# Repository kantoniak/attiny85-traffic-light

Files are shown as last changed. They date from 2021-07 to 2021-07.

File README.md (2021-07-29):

# ATTINY85 traffic light

A simple traffic light implemented using ATTINY85. Lights cycle between configurations and user can move to the next one by pressing a button.

<p align="center">
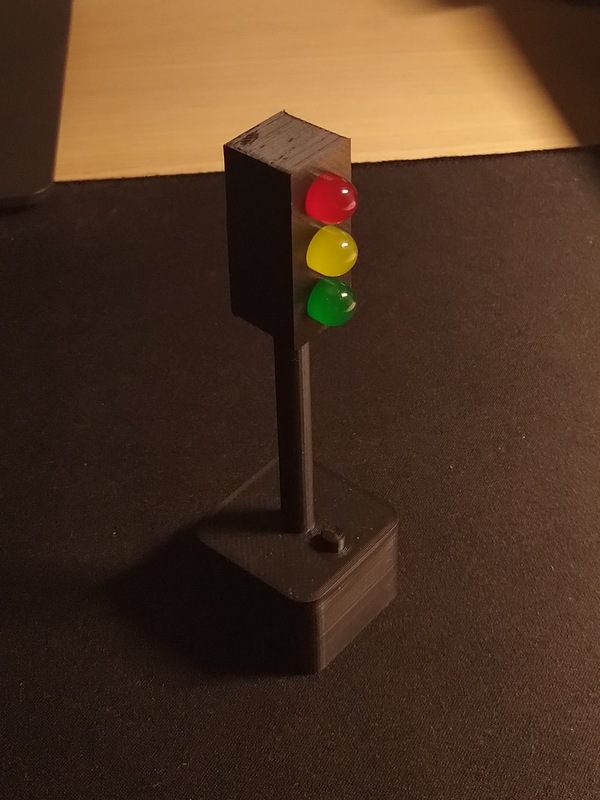
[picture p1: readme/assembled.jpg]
    
</p>

## Hardware

### Electronics

I used big, 10 mm LEDs. The green one has ~3.15V forward voltage and thus the second battery. You don't need it for regular LEDs.

Schematic

BOM:
* ATTINY85 in DIP package;
* 8-leg DIP socket;
* 10 mm LEDs: red, yellow, green;
* 1k, 1k, 330 ohm resistors;
* tactile switch with a pull-up resistor;
* an ON-OFF switch;
* 2x CR2032 battery;
* 20 mm wide PCB.

### Case

Consists of multiple parts for 3D printing in PLA. Print with 20% infill, without supports. See `case/` for Fusion 360 files and exported STLs.

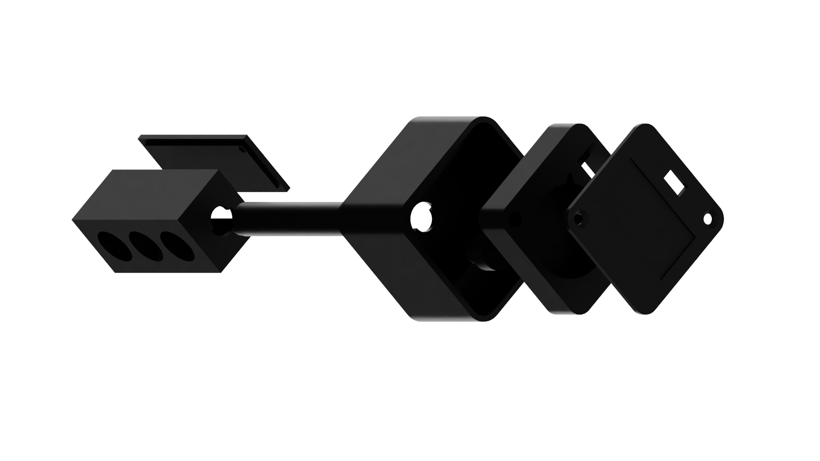
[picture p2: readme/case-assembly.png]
Case render


I wanted to make ATTINY85 replaceable and over-engineered a bit.

Case Assembly BOM:
* 2x M2.5x20 flat-head screw (DIN 965);
* 4x M2x12 flat-head screw (DIN 965);
* 4x M2 hex nuts;
* 2x M2.5 threaded insert, height up to 10 mm (goes into the base);
* 2x M2 threaded insert, height up to 6 mm (goes into the lights back);
* 2x office clip 🙂 (cut and bend to make CR2032 contacts).

## Software

The code is a PlatformIO project. It basically cycles between states after a timeout. The states are as follows, with possible actions marked with colors:
State graph
User can manually move to the next state by pressing a button (the red cycle).
μC will enter deep sleep after 10 minutes since last button press.

### Energy savings

The light runs on a single CR2032 cell capacity (about 220 mAh), so it should consume minimal amounts of energy. Current optimizations are:

* Deep sleep after 10 minutes (commit 0f1c727)
* Disabled ADC (commit dee5303, [blog post](http://www.technoblogy.com/show?KX0))
* Unused pins set to `LOW` (commit dee5303, [forum post](http://gammon.com.au/power))
* Custom fuses settings (commit 2d93b48, [fuse calculator](https://www.engbedded.com/fusecalc/))
  * disabled Brown-Out Detection which does some voltage comparisons
  * 1 MHz clock speed from diving 8 MHz by 8

Remember to set fuses from PlatformIO! It doesn't happen automatically during upload.

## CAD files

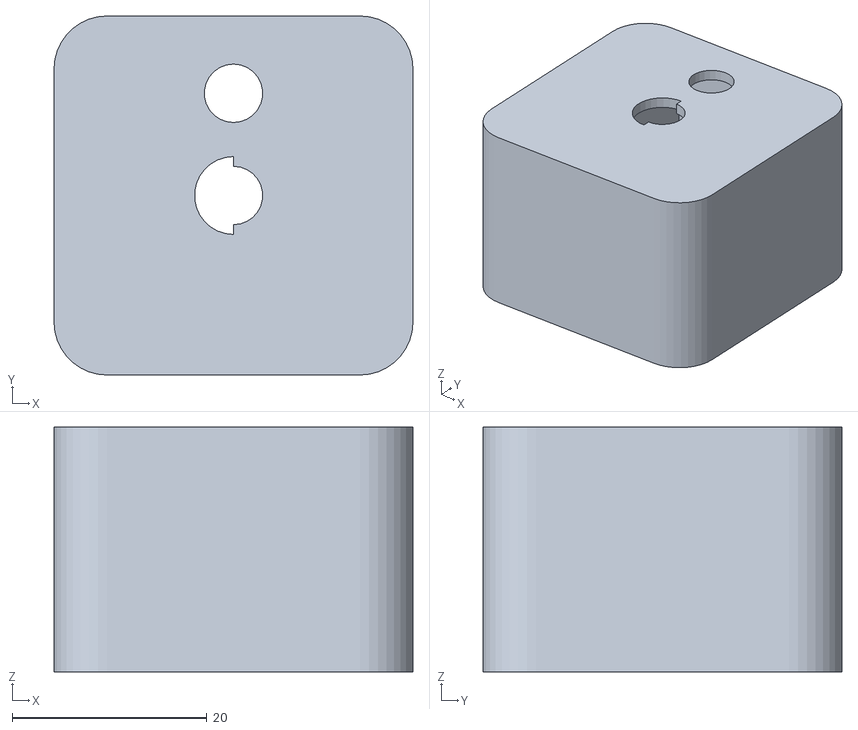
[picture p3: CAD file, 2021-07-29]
case/base.stl
36.9 x 36.9 x 25.1

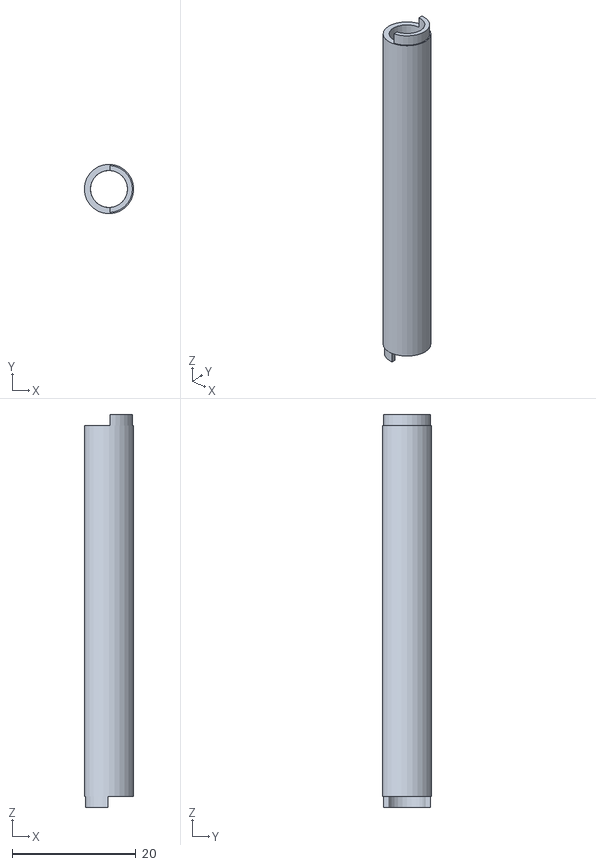
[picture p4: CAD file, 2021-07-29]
case/pole.stl
8.00 x 8.00 x 63.6

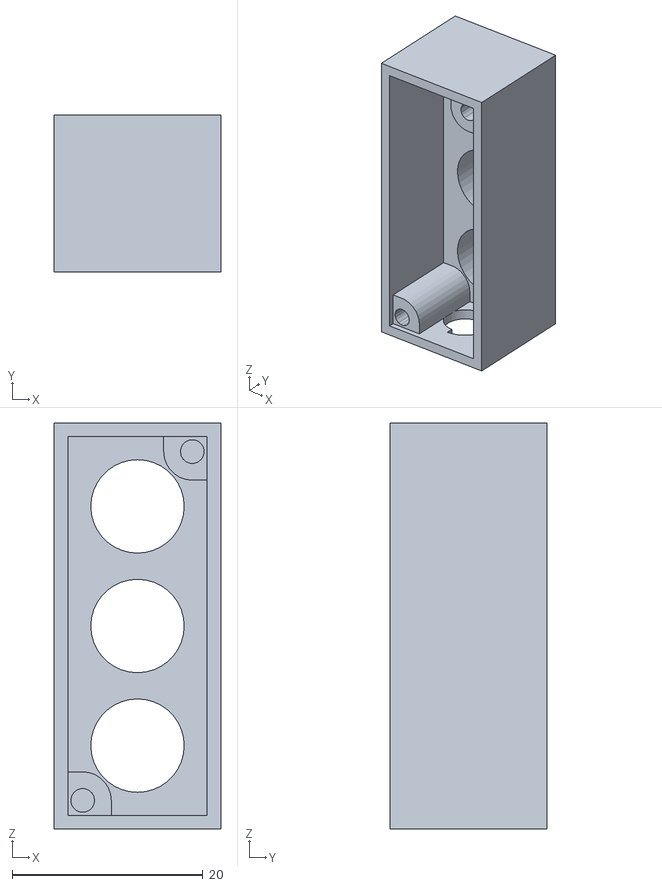
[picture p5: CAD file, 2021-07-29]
case/front.stl
17.5 x 16.5 x 42.6

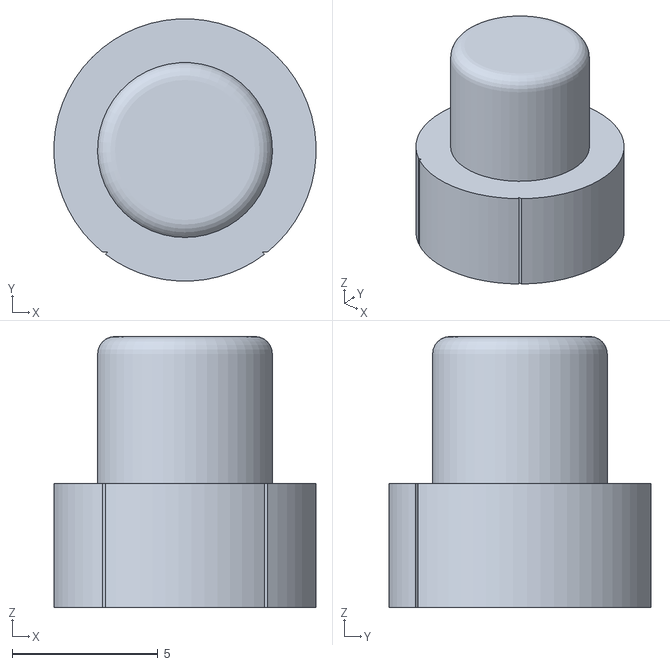
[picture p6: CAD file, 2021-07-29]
case/button.stl
8.99 x 8.99 x 9.30

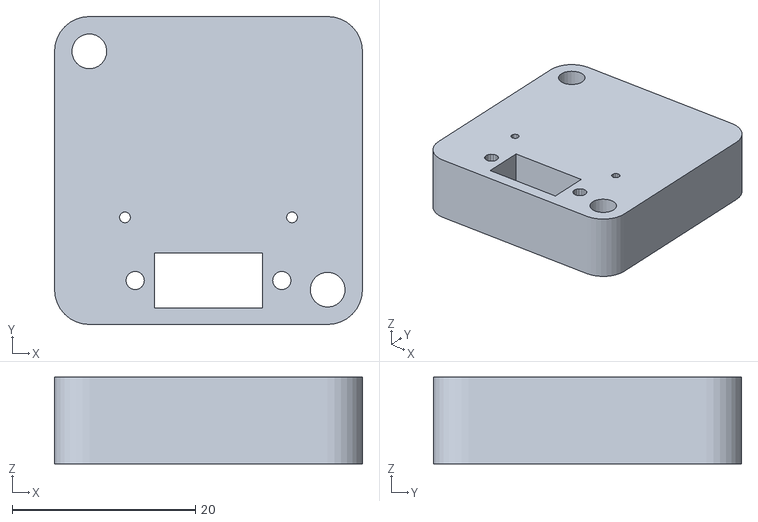
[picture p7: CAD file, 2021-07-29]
case/battery-holder.stl
33.6 x 33.6 x 9.44

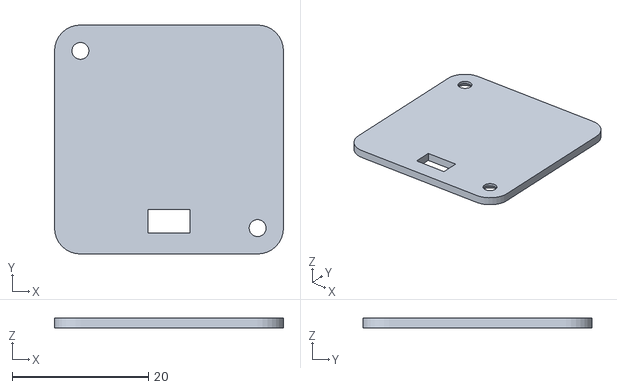
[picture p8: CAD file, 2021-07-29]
case/battery-cover.stl
33.6 x 33.6 x 1.44

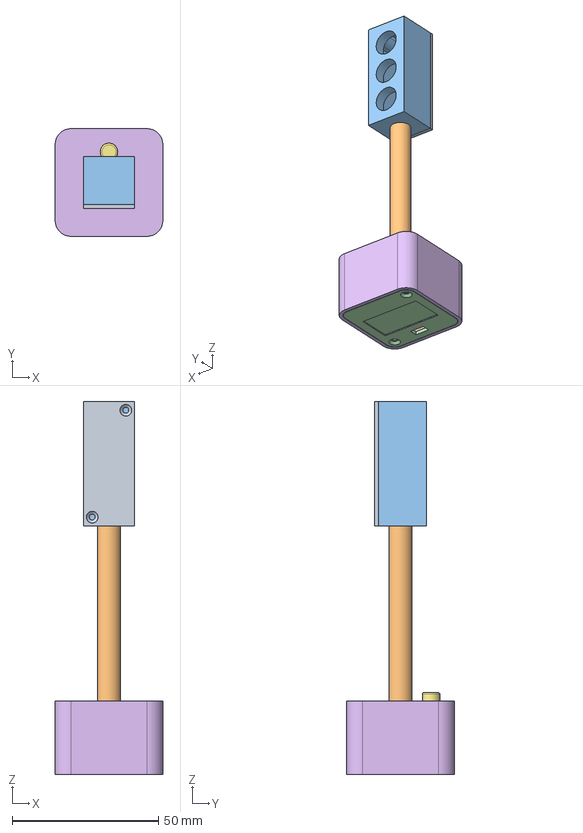
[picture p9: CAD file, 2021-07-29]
case/attiny85-traffic-light.step
36.9 x 36.9 x 127.7 mm

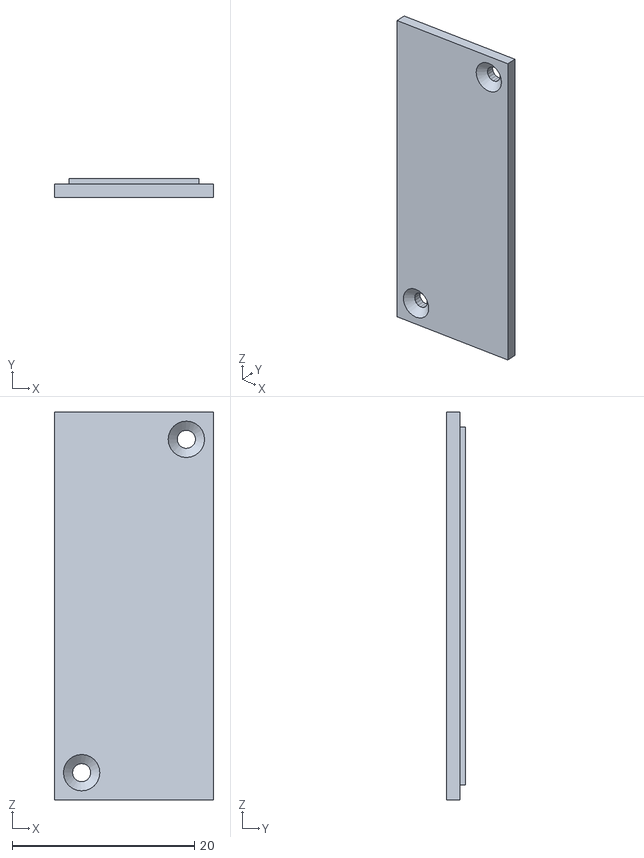
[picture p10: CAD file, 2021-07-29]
case/back.stl
17.5 x 2.04 x 42.6

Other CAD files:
case/attiny85-traffic-light.f3d

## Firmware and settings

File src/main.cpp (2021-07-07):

#include <Arduino.h>

#include "settings.hpp"
#include "states.hpp"

Automaton* automaton;
volatile bool interrupt_active = false;
volatile bool interrupt_flag = false;

void handleInterrupt() {
  interrupt_flag = true;
  detach_button_interrupt(PIN_BUTTON);
  interrupt_active = false;
}

void setup() {
  setup_power_saving();
  init_sleep_mode();
  init_leds();

  interrupt_active = true;
  attach_button_interrupt(PIN_BUTTON, handleInterrupt);

  automaton = new_automaton(millis());
}

void loop() {
  if (interrupt_flag) {
    interrupt_flag = false;
    handle_button(*automaton, millis());
  }

  if (!interrupt_active && digitalRead(PIN_BUTTON) == HIGH) {
    interrupt_active = true;
    attach_button_interrupt(PIN_BUTTON, handleInterrupt);
  }

  update_state(*automaton, millis());
}

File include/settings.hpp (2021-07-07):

#include <Arduino.h>

constexpr uint8_t PIN_BUTTON = 2;
constexpr uint8_t PIN_LED_RED = 3;
constexpr uint8_t PIN_LED_YELLOW = 1;
constexpr uint8_t PIN_LED_GREEN = 0;
constexpr uint8_t PIN_UNUSED_4 = 4;
constexpr uint8_t PIN_UNUSED_5 = 5;

constexpr unsigned long SLEEP_TIMEOUT = 10 * 60 * 1000UL;

constexpr unsigned long STOP_TIMEOUT = 20 * 1000;
constexpr unsigned long STOP_END_TIMEOUT = 1000;
constexpr unsigned long GO_TIMEOUT = 20 * 1000;
constexpr unsigned long GO_END_TIMEOUT = 3 * 1000;

void setup_power_saving();
void init_sleep_mode();
void init_leds();
void attach_button_interrupt(uint8_t pin, void(*handler)(void));
void detach_button_interrupt(uint8_t pin);
void enter_sleep();

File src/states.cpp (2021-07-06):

#include "states.hpp"
#include "settings.hpp"

struct Automaton {
  State state;
  unsigned long state_timeout;
  unsigned long global_timeout;
};

void initialLedSequence() {
  digitalWrite(PIN_LED_RED, HIGH);
  delay(200);
  digitalWrite(PIN_LED_RED, LOW);
  delay(100);
  digitalWrite(PIN_LED_YELLOW, HIGH);
  delay(200);
  digitalWrite(PIN_LED_YELLOW, LOW);
  delay(100);
  digitalWrite(PIN_LED_GREEN, HIGH);
  delay(200);
  digitalWrite(PIN_LED_GREEN, LOW);
}

Automaton* new_automaton(unsigned long current_time) {
  Automaton* automaton = new Automaton;
  automaton->global_timeout = current_time + SLEEP_TIMEOUT;
  enter_state(*automaton, INIT, current_time);
  return automaton;
}

void delete_automaton(Automaton* automaton) {
  delete automaton;
}

void enter_state(Automaton & automaton, State state, unsigned long current_time) {
  automaton.state = state;
  automaton.state_timeout = 0;
  switch (automaton.state) {
    case INIT: {
      initialLedSequence();
      enter_state(automaton, STOP, current_time);
      break;
    }
    case STOP: {
      digitalWrite(PIN_LED_RED, HIGH);
      automaton.state_timeout = current_time + STOP_TIMEOUT;
      break;
    }
    case STOP_END: {
      digitalWrite(PIN_LED_RED, HIGH);
      digitalWrite(PIN_LED_YELLOW, HIGH);
      automaton.state_timeout = current_time + STOP_END_TIMEOUT;
      break;
    }
    case GO: {
      digitalWrite(PIN_LED_GREEN, HIGH);
      automaton.state_timeout = current_time + GO_TIMEOUT;
      break;
    }
    case GO_END: {
      digitalWrite(PIN_LED_YELLOW, HIGH);
      automaton.state_timeout = current_time + GO_END_TIMEOUT;
      break;
    }
    case SLEEP: {
      enter_sleep();
      break;
    }
    default: {
      break;
    }
  }
}

void leave_state(Automaton & automaton) {
  switch (automaton.state) {
    case STOP: {
      digitalWrite(PIN_LED_RED, LOW);
      break;
    }
    case STOP_END: {
      digitalWrite(PIN_LED_RED, LOW);
      digitalWrite(PIN_LED_YELLOW, LOW);
      break;
    }
    case GO: {
      digitalWrite(PIN_LED_GREEN, LOW);
      break;
    }
    case GO_END: {
      digitalWrite(PIN_LED_YELLOW, LOW);
      break;
    }
    default: {
      break;
    }
  }
}

void update_state(Automaton & automaton, unsigned long current_time) {

  // Go to sleep if no activity
  if (current_time >= automaton.global_timeout) {
    leave_state(automaton);
    enter_state(automaton, SLEEP, current_time);
    return;
  }

  switch (automaton.state) {
    case STOP: {
      if (current_time >= automaton.state_timeout) {
        leave_state(automaton);
        enter_state(automaton, STOP_END, current_time);
      }
      break;
    }
    case STOP_END: {
      if (current_time >= automaton.state_timeout) {
        leave_state(automaton);
        enter_state(automaton, GO, current_time);
      }
      break;
    }
    case GO: {
      if (current_time >= automaton.state_timeout) {
        leave_state(automaton);
        enter_state(automaton, GO_END, current_time);
      }
      break;
    }
    case GO_END: {
      if (current_time >= automaton.state_timeout) {
        leave_state(automaton);
        enter_state(automaton, STOP, current_time);
      }
      break;
    }
    default: {
      break;
    }
  }
}

void handle_button(Automaton & automaton, unsigned long current_time) {
  automaton.global_timeout = current_time + SLEEP_TIMEOUT;

  switch (automaton.state) {
    case STOP: {
      leave_state(automaton);
      enter_state(automaton, STOP_END, current_time);
      break;
    }
    case STOP_END: {
      leave_state(automaton);
      enter_state(automaton, GO, current_time);
      break;
    }
    case GO: {
      leave_state(automaton);
      enter_state(automaton, GO_END, current_time);
      break;
    }
    case GO_END: {
      leave_state(automaton);
      enter_state(automaton, STOP, current_time);
      break;
    }
    case SLEEP: {
      leave_state(automaton);
      enter_state(automaton, STOP, current_time);
    }
    default: {
      break;
    }
  }
}

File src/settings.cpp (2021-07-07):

#include <avr/sleep.h>
#include "settings.hpp"

#define adc_disable() (ADCSRA &= ~(1<<ADEN))

void setup_power_saving() {
  // Disable ADC
  adc_disable();

  // Set unused pins low so they don't float
  pinMode(PIN_UNUSED_4, OUTPUT);
  pinMode(PIN_UNUSED_5, OUTPUT);
  digitalWrite(PIN_UNUSED_4, LOW);
  digitalWrite(PIN_UNUSED_5, LOW);
}

void init_sleep_mode() {
  set_sleep_mode(SLEEP_MODE_PWR_DOWN);
  noInterrupts();
  sleep_enable();
  interrupts();
}

void init_leds() {
  pinMode(PIN_LED_RED, OUTPUT);
  pinMode(PIN_LED_YELLOW, OUTPUT);
  pinMode(PIN_LED_GREEN, OUTPUT);
  digitalWrite(PIN_LED_RED, LOW);
  digitalWrite(PIN_LED_YELLOW, LOW);
  digitalWrite(PIN_LED_GREEN, LOW);
}

void attach_button_interrupt(uint8_t pin, void(*handler)(void)) {
  pinMode(pin, INPUT);
  attachInterrupt(digitalPinToInterrupt(pin), handler, LOW);
}

void detach_button_interrupt(uint8_t pin) {
  detachInterrupt(digitalPinToInterrupt(pin));
}

void enter_sleep() {
  interrupts();
  sleep_cpu();
}

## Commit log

2021-07-03 Implement basic interrupt example
2021-07-06 Add other LEDs
2021-07-06 Implement switching states through a button
2021-07-07 Optimize power usage
    * Set unused pins to LOW
    * Disable ADC
2021-07-07 Set custom fuses
2021-07-29 Add case files
    [attiny85-traffic-light.f3d, attiny85-traffic-light.step, back.stl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]
